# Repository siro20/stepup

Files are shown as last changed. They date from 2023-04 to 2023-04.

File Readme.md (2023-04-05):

# Non-isolated 12V to 120V boost converter

This project is about finding a power supply to drive regular 240V/120V
LED bulbs from a 12V power supply or 12V battery.

This is the first prototype build using the [LM3478](https://www.ti.com/product/de-de/LM3478).

It features:
- Up to 36 Watts
- Inrush current limit
- LC input filter
- Follows TI's reference design

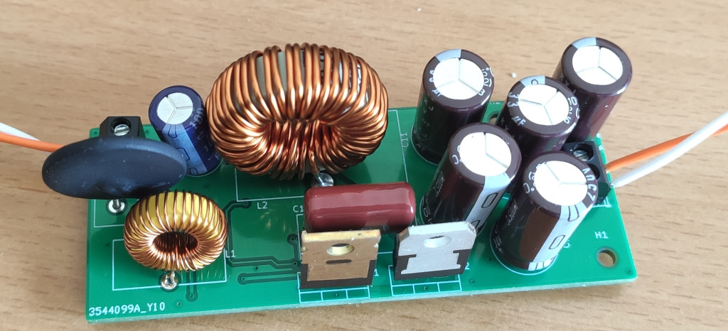
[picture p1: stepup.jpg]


## Analysis

The boost converter was found working and it outputs 120VDC.

**WARNING**: The project was abadonned due to the undocumented behaviour of the LM3478!

- The LM3478 has no soft-start mechanism.
- The LM3478 starts to operate at 3V at Vin
- The LM3478 gate drive voltage is quite low with 7.2V or less

**At startup the LM3478 doesn't operate at all. It just pulls the gate drive high and
waits for an over-current condition. Once the over-current conditions happens it
starts operating in PWM mode.**

**The board draws more than 40Watts without starting to switch the Mosfet as the current
limit isn't reached.**

## kicad board files

The PCB has dimensions of 32mmx82mm:

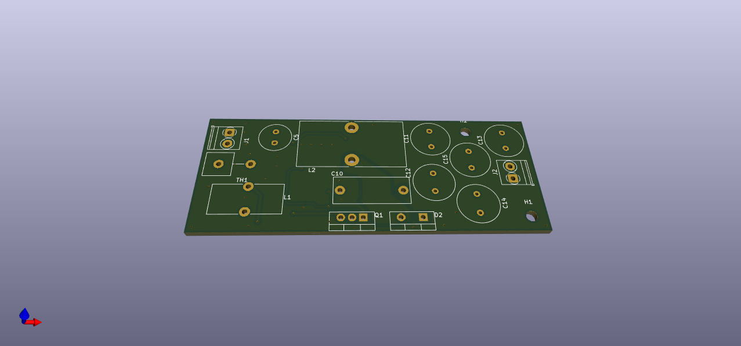
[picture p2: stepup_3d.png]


The schematic [available as PDF here](schematics/stepup.pdf) is following the reference design:



## Disclaimer

    THE OPEN SOURCE SOFTWARE/HARDWARE IN THIS PROJECT IS DISTRIBUTED
    IN THE HOPE THAT IT WILL BE USEFUL, BUT WITHOUT ANY WARRANTY, WITHOUT
    EVEN THE IMPLIED WARRANTY OF MERCHANTABILITY OR FITNESS FOR A
    PARTICULAR PURPOSE.

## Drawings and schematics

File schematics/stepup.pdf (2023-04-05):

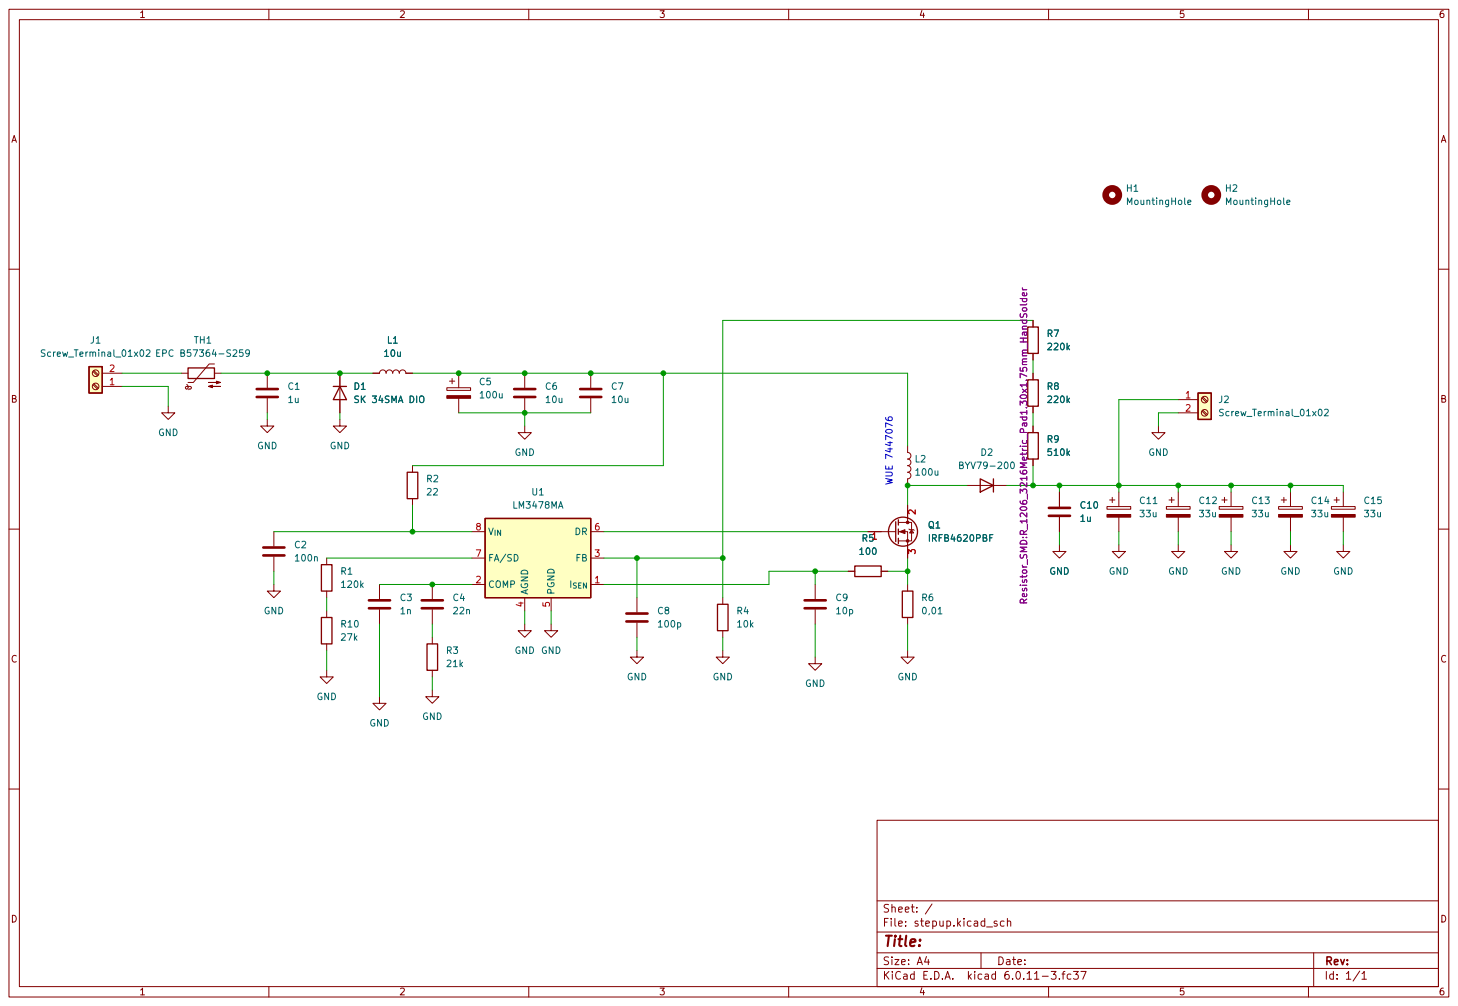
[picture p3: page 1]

Id: 1/1 Title: File: stepup.kicad_sch Sheet: / C8

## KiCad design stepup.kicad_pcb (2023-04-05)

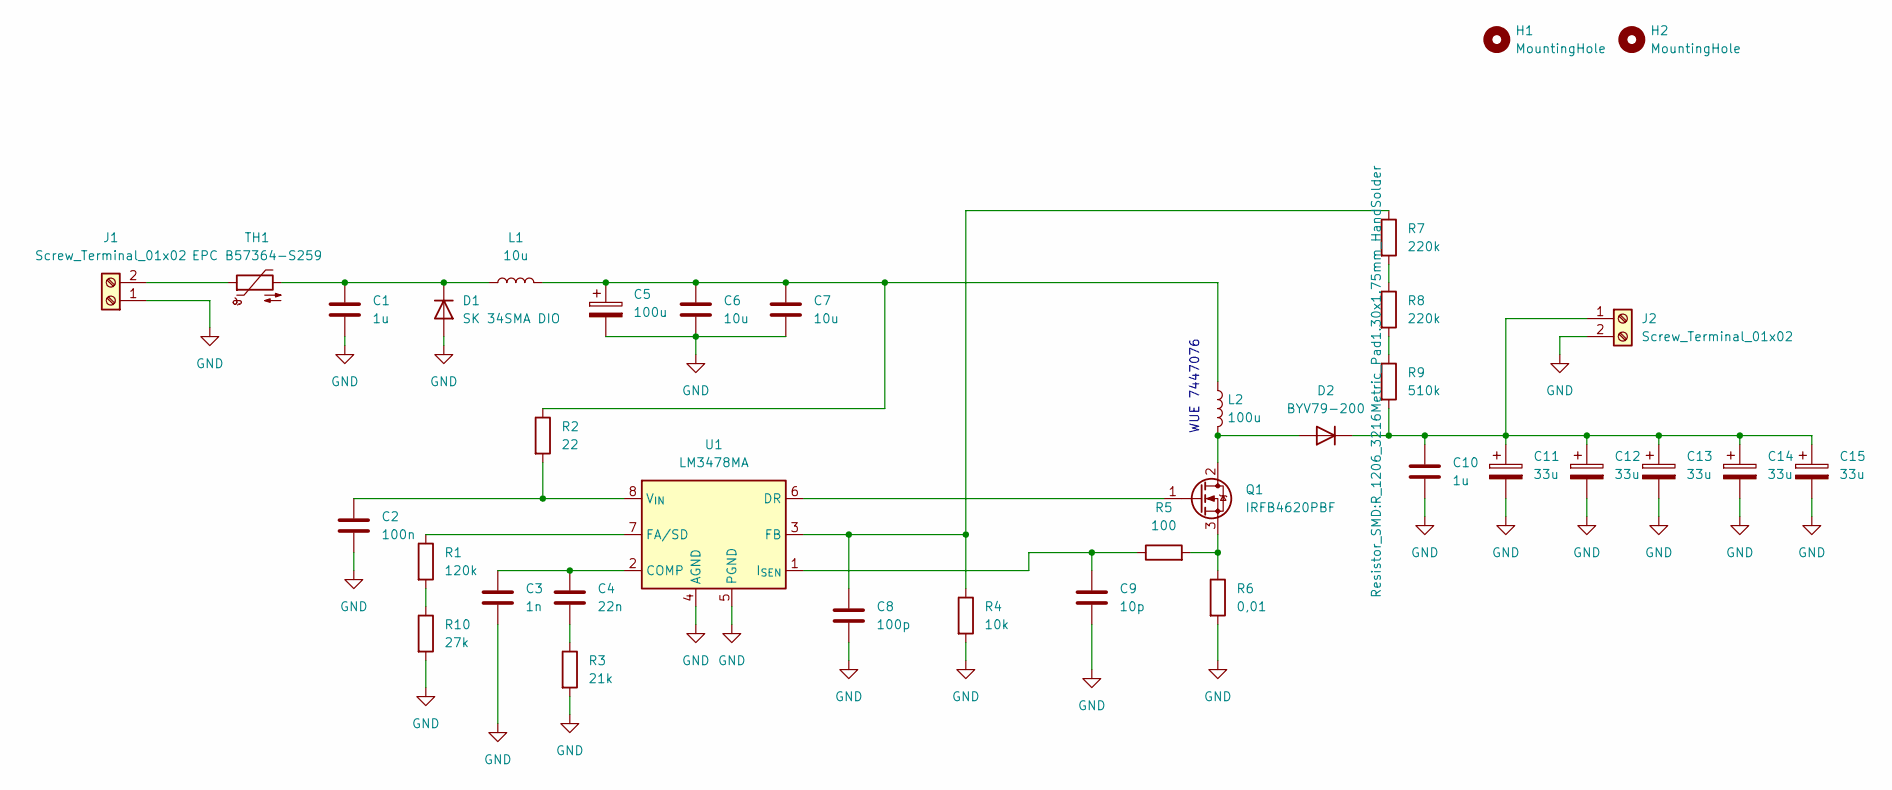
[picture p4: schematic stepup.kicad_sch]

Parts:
C1: 1u; R_0805_2012Metric_Pad1.20x1.40mm_HandSolder
C2: 100n; C_0805_2012Metric_Pad1.18x1.45mm_HandSolder
C3: 1n; C_0603_1608Metric_Pad1.08x0.95mm_HandSolder
C4: 22n; C_0603_1608Metric_Pad1.08x0.95mm_HandSolder
C5: 100u; C_Radial_D8.0mm_H11.5mm_P3.50mm
C6, C7: 10u; R_1210_3225Metric_Pad1.30x2.65mm_HandSolder
C8: 100p; C_0603_1608Metric_Pad1.08x0.95mm_HandSolder
C9: 10p; C_0603_1608Metric_Pad1.08x0.95mm_HandSolder
C10: 1u; C_Rect_L18.0mm_W7.0mm_P15.00mm_FKS3_FKP3
C11, C12, C13, C14, C15: 33u; C_Radial_D10.0mm_H20.0mm_P5.00mm
D1: SK 34SMA DIO; D_SMA
D2: BYV79-200; TO-220-2_Vertical
H1, H2: MountingHole; MountingHole_2.7mm_M2.5
J1, J2: Screw_Terminal_01x02; TerminalBlock_Phoenix_PT-1,5-2-3.5-H_1x02_P3.50mm_Horizontal
L1: 10u; L_Toroid_Vertical_L16.4mm_W7.6mm_P6.60mm_Vishay_TJ3
L2: 100u; L_Toroid_Vertical_L26.7mm_W14.0mm_P10.16mm_Pulse_D
Q1: IRFB4620PBF; TO-220-3_Vertical
R1: 120k; R_0805_2012Metric_Pad1.20x1.40mm_HandSolder
R2: 22; R_0805_2012Metric_Pad1.20x1.40mm_HandSolder
R3: 21k; R_0805_2012Metric_Pad1.20x1.40mm_HandSolder
R4: 10k; R_0805_2012Metric_Pad1.20x1.40mm_HandSolder
R5: 100; R_0805_2012Metric_Pad1.20x1.40mm_HandSolder
R6: 0,01; R_1206_3216Metric_Pad1.30x1.75mm_HandSolder
R7, R8: 220k; R_1206_3216Metric_Pad1.30x1.75mm_HandSolder
R9: 510k; R_1206_3216Metric_Pad1.30x1.75mm_HandSolder
R10: 27k; R_0805_2012Metric_Pad1.20x1.40mm_HandSolder
TH1: EPC B57364-S259; R_Axial_Power_L20.0mm_W6.4mm_P7.62mm_Vertical
U1: LM3478MA; SOIC-8_3.9x4.9mm_P1.27mm

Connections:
GND: C1.2, C2.2, C3.2, C5.2, C6.2, C7.2, C8.2, C9.2, C10.2, C11.2, C12.2, C13.2, C14.2, C15.2, D1.2 (A), J1.1, J2.2, R3.2, R4.2, R6.2, R10.2, U1.4 (AGND), U1.5 (PGND)
unnamed: C1.1, D1.1 (K), L1.1, TH1.2
unnamed: C2.1, R2.2, U1.8 (V_{IN})
unnamed: C3.1, C4.1, U1.2 (COMP)
unnamed: C4.2, R3.1
unnamed: C5.1, C6.1, C7.1, L1.2, L2.1, R2.1
unnamed: C8.1, R4.1, R7.1, U1.3 (FB)
unnamed: C9.1, R5.1, U1.1 (I_{SEN})
unnamed: C10.1, C11.1, C12.1, C13.1, C14.1, C15.1, D2.1 (K), J2.1, R9.2
unnamed: D2.2 (A), L2.2, Q1.2 (D)
unnamed: J1.2, TH1.1
unnamed: Q1.1 (G), U1.6 (DR)
unnamed: Q1.3 (S), R5.2, R6.1
unnamed: R1.1, U1.7 (FA/SD)
unnamed: R1.2, R10.1
unnamed: R7.2, R8.1
unnamed: R8.2, R9.1

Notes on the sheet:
WUE 7447076

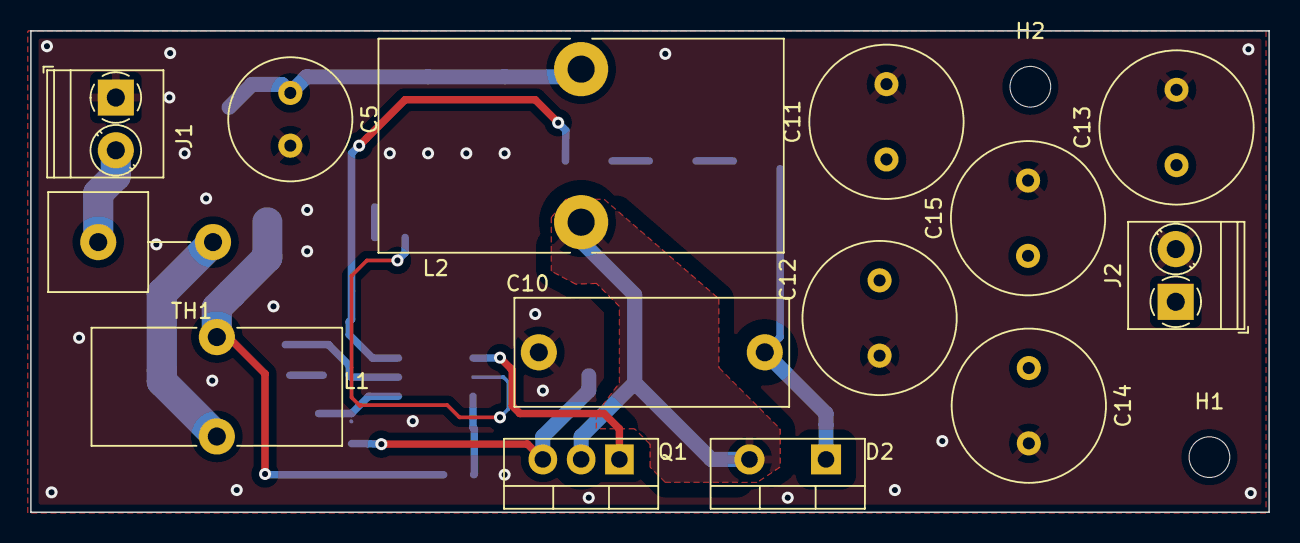
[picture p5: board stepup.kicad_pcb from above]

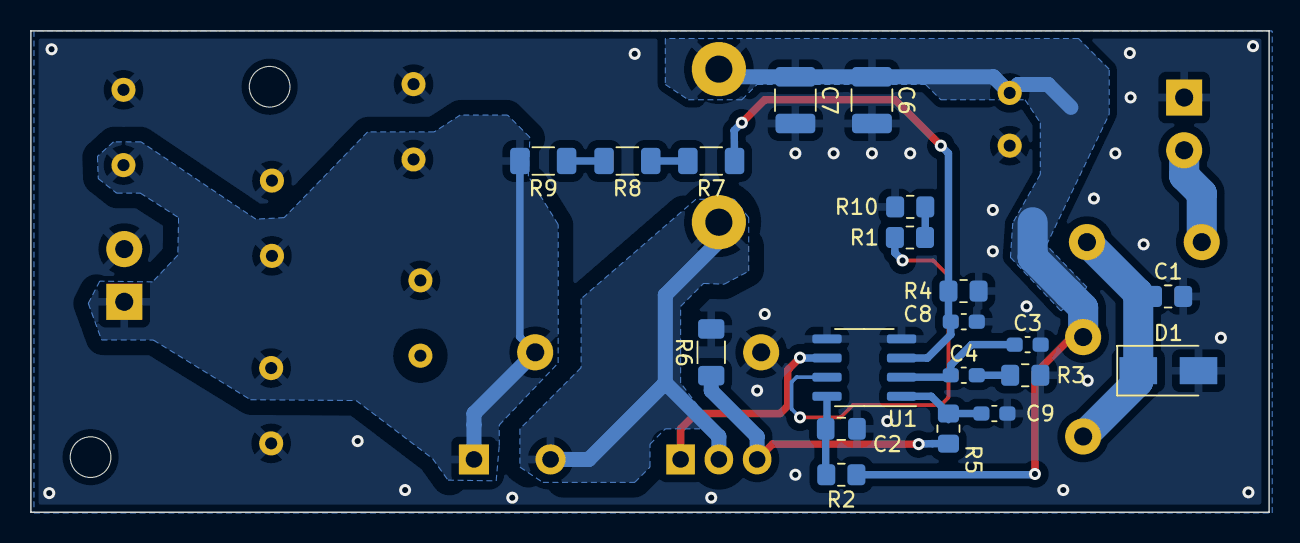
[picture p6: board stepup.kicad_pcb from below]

Board: 2 copper layers, 82.2 x 32.0 mm, 36 parts (20 on the bottom side), 17 nets.
